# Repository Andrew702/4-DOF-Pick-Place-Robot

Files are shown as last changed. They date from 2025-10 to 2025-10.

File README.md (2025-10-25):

# 📦 4-DOF Pick & Place robotic arm

_A 4DOF scara robot with a gripping head for picking and placing products in an assembly line_

---

## 🧠 Overview

- This is my project fot the robotics, automatic control, and MCT system design courses, it uses simple manufactured parts and cheap components.
- A study for actuator sizes is done as the model is exported to matlab.
- We use ROS for manipulating the Arm efficiently.

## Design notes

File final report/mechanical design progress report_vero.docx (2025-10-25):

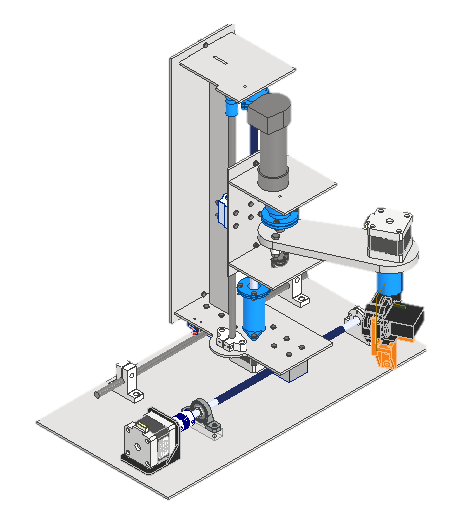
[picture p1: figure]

Mechatronics System Design

Name | ID
Andrew Hany Sobhy | 1900440
Abanoub Masrour Mehawed | 1901055
Veronia Ibrahim Mikhael | 1900463
John Sameh Sobhi | 1900907
Caren Mahrous Zakhary | 1901503
Zyad Wahied Kamel | 1700575

mechanical design report

submitted to:

Eng. Hossam Elkeshky

Eng. Mohab Ahmed

Eng. Zeyad Hazem

# Introduction

# 1. Robots in industrial field

An industrial robot is an autonomous system of sensors, controllers, and actuators on an articulated frame that executes specific functions and operations in a manufacturing or processing line. They operate continuously through repetitive movement cycles as instructed by a set of commands called a program. These machines minimize or eliminate the human factor to gain various advantages in processing speed, capacity, and quality.

# 1. What is a VDI model

Figure 1 VDI model

# VDI Model

# 1. System Requirements

1. The robot weight is less than 7.5 kg

2. size must not exceed 0.04 cubic meter

3. graphical user interface: user friendly

# 2. System design

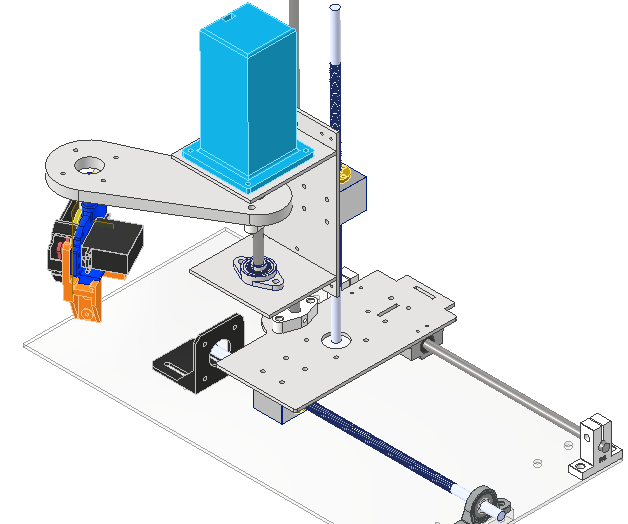
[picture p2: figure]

For the system some decisions were taken according to the system requirements as

1. The 4 degrees of freedom will be divided into 2 prismatic joints (motion in x-axis , motion in z-axis) and 2 revolute joints (rotation about z-axis, rotation about end effector z-axis )
2. Application for robot is pick and place.
3. Number of motors → 5
1. Dc motor with encoder for the revolute joint
2. 3 stepper motors
3. Servo motor for the end effector
4. A microcontroller is needed to control the motor and its motion. (Arduino)
5. A PCB must be implemented to insure firm wiring.
6. ROS will be used as a communication protocol between microcontrollers and other electronic devices.

# 2. Domain specific design

## 1. Mechanical design

### 1. Joint #1 (Prismatic):

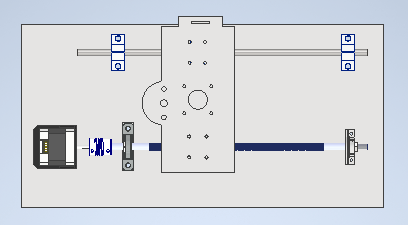
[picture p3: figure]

- Design:

Figure 2 joint 1 isometric view

Figure 3 joint 1 plan view.

- Operation and support:

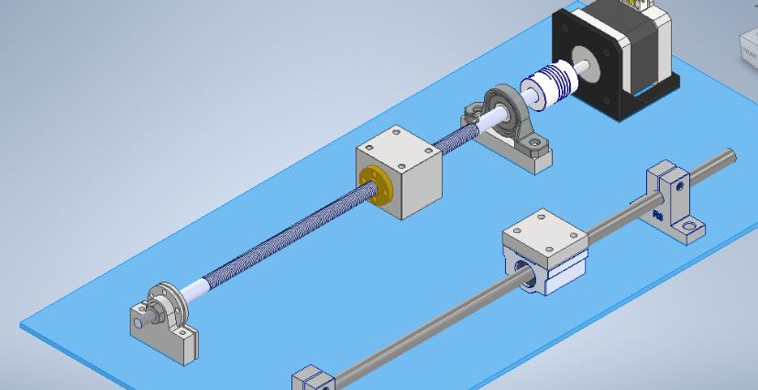
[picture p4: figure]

- Motion is Governed by a nema 17 motor coupled to a lead screw and guide nut to transform rotational motion into translational motion to carry the base in the Y Axis direction.

Figure 4 joint 1 motion

- Bearings used : 3 ( 2 ball bearing , 1 linear bearing)
- Lead Screw and motor shaft are supported by 2 Plummer blocks at each end of the lead screw and the base is moved along a supporting rod attached jointed by a linear bearing.

Figure 5 joint 1 motor support floating bearing

- Motor support:
  1. floating bearing:
- motion is transmitted to the lead screw using coupling between motor shaft and lead screw.
- Plummer block is used as the floating bearing.
  2. Fixed bearing:

Deep grove ball bearing fixed from 4 points ( shoulder

in lead screw, 2 shoulder in bearing cover, Nut)

Figure 6 joint 1 motor support fixed bearing

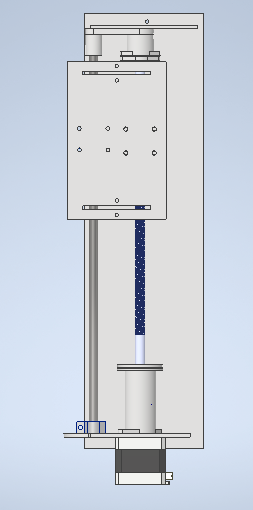
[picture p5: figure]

### 2. Joint #2 (Prismatic):

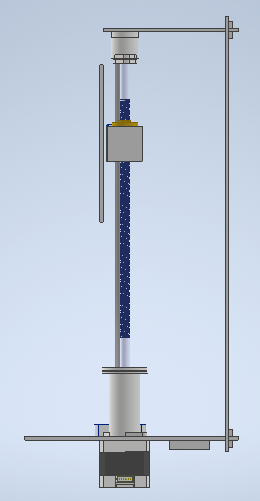
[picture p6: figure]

- Design:

Figure 7 joint 2 front view

Figure 8 joint 2 side view

Figure 9 joint 2 isometric view

- Operation and support

Motion is Governed by a nema 17 motor coupled to a lead screw and guide nut to transform rotational motion into translational motion to carry the Revolute joint in the Z Axis direction .

Revolute joint is attached to the cart by guide nut housing and Linear bearing block Via bolts and nuts , The cart is also supported on a linear rod.

- Motor support
- Fixed

Deep Groove ball bearing Fixed on 4 points by ( Snap Ring , Housing shoulder, Power screw shoulder ,Cover)

Figure 10 joint 2 motor support fixed bearing

- Floating

Deep Groove ball bearing Fixed on 2 points by (Housing Shoulder, Cover)

Figure 11 joint 2 motor support floating bearing

### 3. Joint #3 (Revolute):

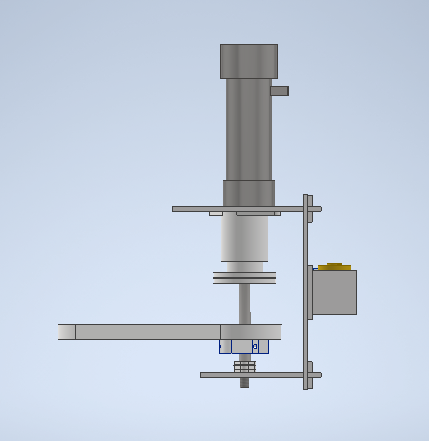
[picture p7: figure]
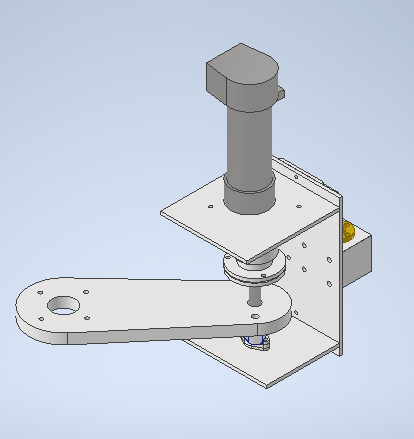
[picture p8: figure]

- Design:

Figure 12 joint 3 isometric view

Figure 13 joint 3 side view

- Operation and support:

Motion is Governed by a DC motor coupled to a rod and the rotation of rod is transferred to the joint by a pin connection to rotate around Z axis.

- Motor Support:
- Fixed

Deep Groove ball bearing Inside a flanged cover Fixed on 4 points by ( Nut, Housing shoulder, Power screw shoulder, Cover)

Figure 14 joint 3 motor support fixed bearing

- Floating

Figure 15 motor support floating bearing

Deep Groove ball bearing Fixed on 2 points by (Housing Shoulder, Cover)

### 4. Joint #4 (Revolute & End Effector):

- Design:

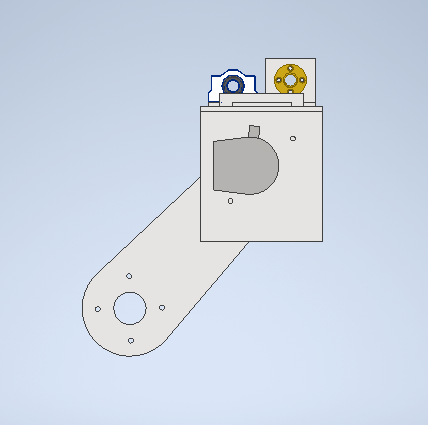
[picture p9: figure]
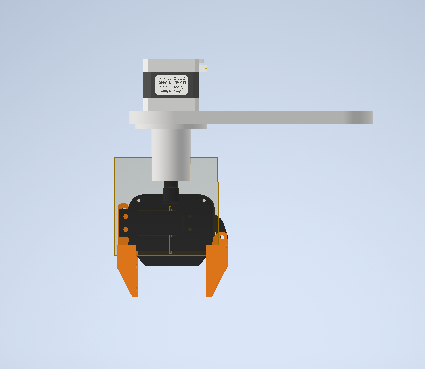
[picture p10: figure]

Figure 16 joint 4 side view

Figure 17 joint 4 plan view

- Operation and support:

Motion is Governed by a Nema 17 motor coupled to End Effector shaft to allow the end effector to rotate around Z axis .

End Effector has a servo motor attached to it to control the gripping action.

- Motor support:

Figure 18 joint 4 motor support bearing

Thrust ball bearing Inside a cover fixed on 2 points by (Coupler, Housing shoulder)

### 5. Bill of material:

component | qty | cost | store | specifications
lead screw | 2 | 60 | lancer | 30cm , 8mm
nut block | 2 | 70 | lancer | 8mm
lead screw nut | 2 | 30 | lancer | 2starts, 8mm
shaft | 3 | 40 | uge_helo. | 8mm * 333 length
linear bearing block | 2 | 50 | lancer | 8mm
vertical shaft support | 2 | 60 | | 8mm , 3d printing
horizontal shaft support | 2 | 60 | | 8mm , 3d printing
plumer block horizontal | 1 | 0 | | 6mm , 3d printing
plumer block horizontal | 1 | 40 | lancer | 8mm
plumer block vertical | 1 | 0 | | 6mm , 3d printing
Linear gripper | 1 | 0 | | End Effector 3d printing
nema 17 holder | 1 | 40
coupler 5*8 | 1 | 45 | lancer
coupler 6.35*10 | 1 | 70 | future | 10 OOS , 8 Available
nema 17 | 1 | 60 | lancer | used, 2 left
dc motor | 1 | 0 | john
Servo motor | 1 | 0 | caren
Nema 17 cable with Dupont | 1 | 20 | lancer
A4988 Driver | 1 | 50 | lancer | 2left
ball bearing (8*16) | 2 | 20 | twfi2ia | width 4
ball bearing (6*13) | 1 | 20 | twfi2ia | width 3.5
ball bearing (6*19) | 1 | 20 | twfi2ia | width 6
thrust bearing (10*24) | 1 | 20 | twfi2ia | width 9
snap ring | 1 | 0 | | shaft 6
bolts M4*1.6 | 8 | 1 | lancer
nema 17 screw set | 10 | 1 | lancer
bolts M3*1 | 8 | 1 | lancer
M6 nuts | 2 | 0

## 2. Actuator Sizing

### 1. Motor 1

Figure 19: motor 1 in matlab view

Type: Stepper motor (so we don’t need feedback or encoder to achieve accurate positioning with high torque)

Inertia: J_(horizontal cart) +J_(leadscrew asm) +J_(rotor) =9.8×10^(-6) kg.m^2

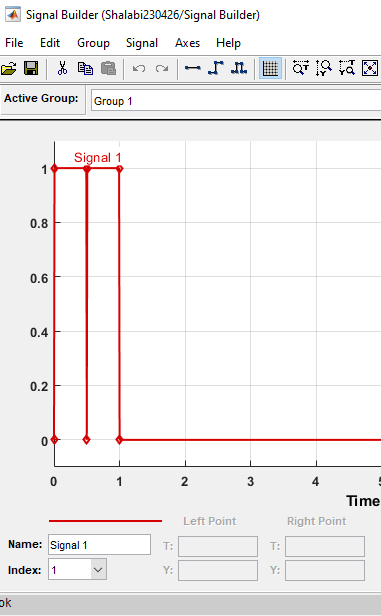
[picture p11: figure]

Motion Profile:

Figure 20: Velocity Profile for motor 1

- max velocity = 300 rpm = 31.41 rad/s
- signal is in the form of trapezoidal pulses with acceleration time = 0.0077 seconds.

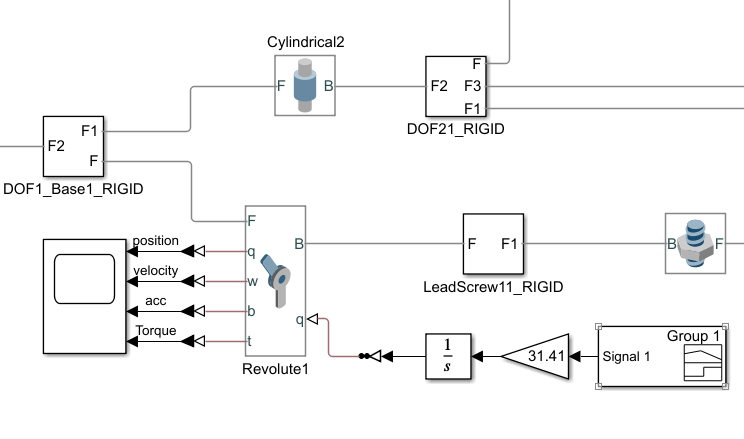
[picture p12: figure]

Figure 21: Connection configuration for motor 1

Figure 22: Torque Profile for motor 1

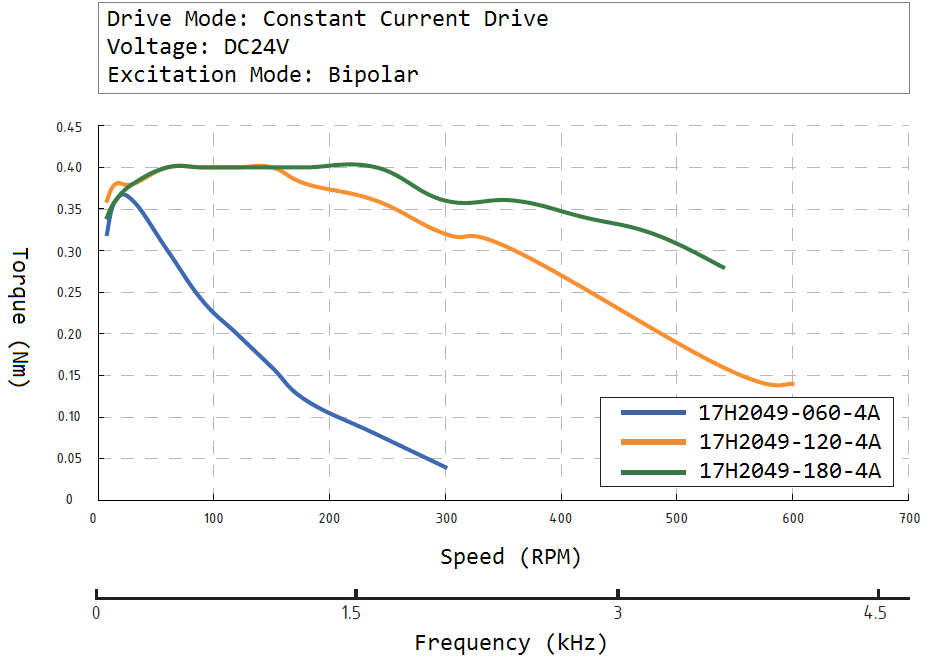
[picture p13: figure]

Torque: As we can see from the graph above the peak torque is at 0.04 N.m, one stepper motor that’s suitable for this torque at 300 rpm is the NEMA-17H2049-060-4A, which will provide a maximum speed of 300 rpm this gives us an acceleration time of 0.0077 seconds as mentioned above and the velocity profile matches exactly, except for the number of steps (pulses) given to the motor each second (2 steps are only demonstrated).

Figure 23: NEMA-17 Torque Speed characteristics

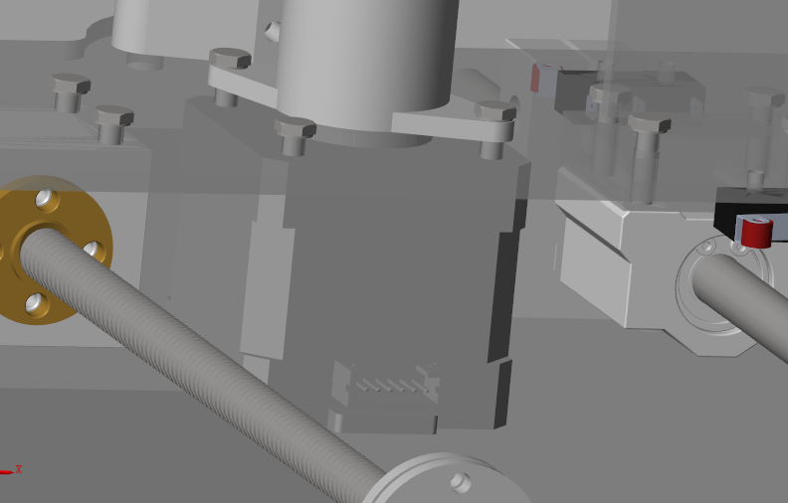
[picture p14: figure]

### 6. Motor 2

Figure 24: motor 2 in matlab view

Figure 25: motor 2 another view

Type: Stepper motor (so we don’t need feedback or encoder to achieve accurate positioning with high torque)

Inertia: J_(vertical cart) +J_(leadscrew asm) +J_(rotor) =9.72×10^(-6) kg.m^2

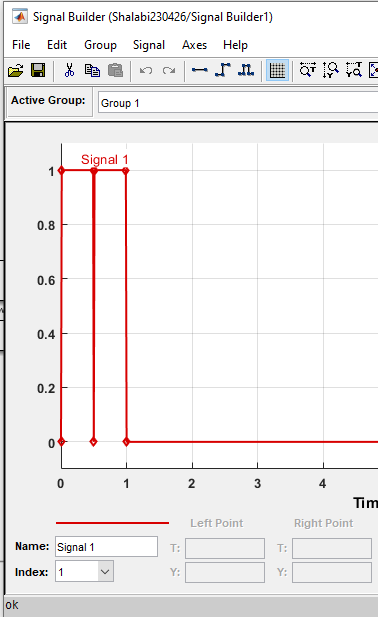
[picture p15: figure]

Motion Profile:

- max velocity = 300 rpm = 31.41 rad/s

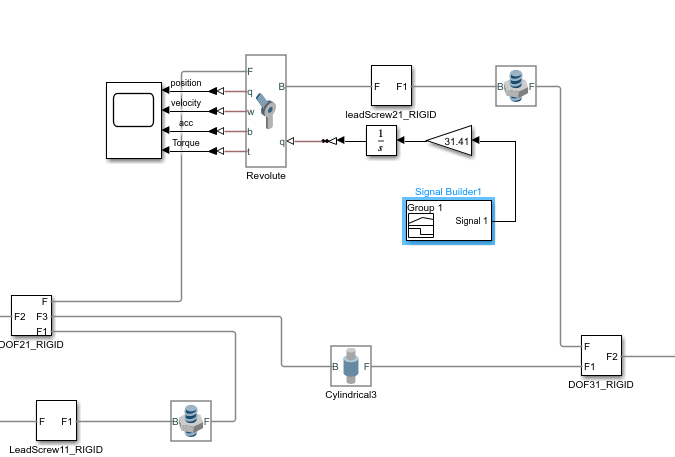
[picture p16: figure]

- signal is in the form of trapezoidal pulses with acceleration time = 0.01137 seconds.

Figure 26: Figure 27: Connection configuration for motor 2

Figure 28: Velocity Profile for motor 2

Figure 29: Torque Profile for motor 2

Torque: As we can see from the graph above the peak torque is at 0.04 N.m, at also 300 rpm this allows us to also use the NEMA-17 stepper motor as motor 1 (2 steps are only demonstrated in the above graph).

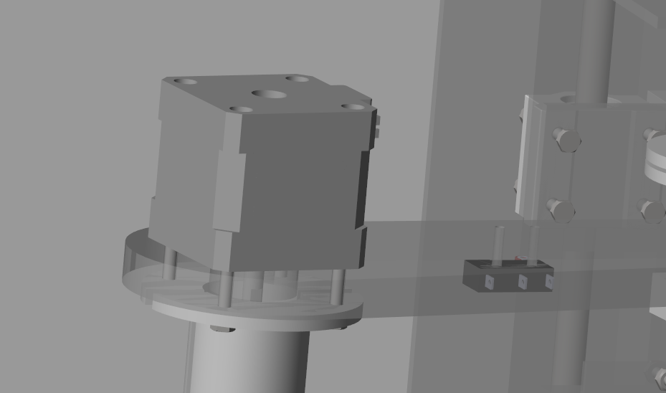
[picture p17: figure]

### 7. Motor 3

Figure 30: motor 3 in matlab view

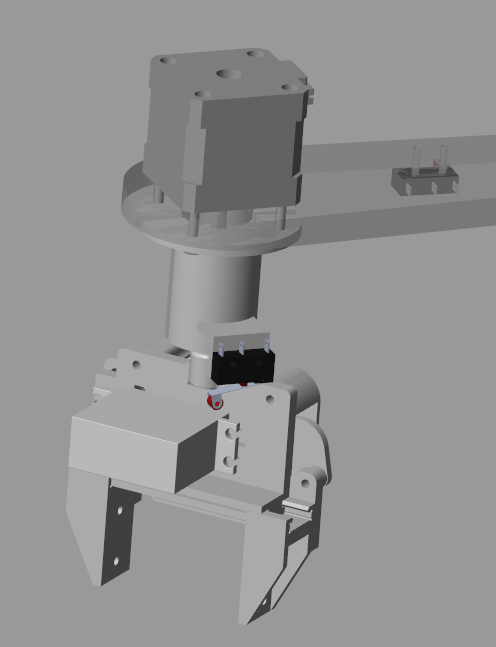
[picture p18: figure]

Figure 31: motor 3 another view

Type: Stepper motor (so we don’t need feedback or encoder to achieve accurate positioning with high torque)

Inertia: J_(Coupler+gripper) +J_(rotor) =9.88×10^(-5) kg.m^2

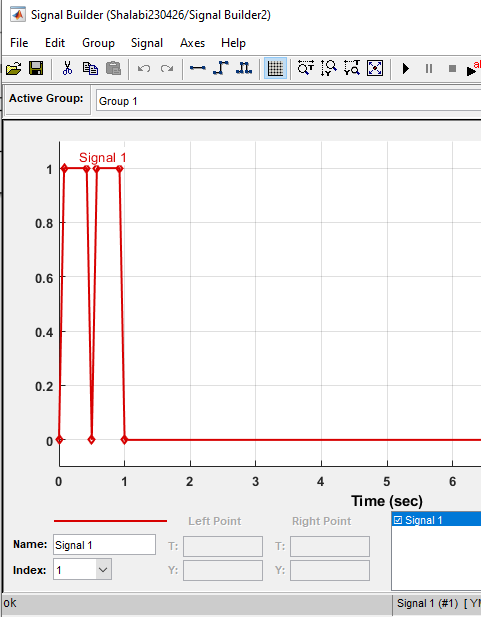
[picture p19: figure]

Motion Profile:

Figure 32: Figure 33: Figure 34: Connection configuration for motor 2

- max velocity = 300 rpm = 31.41 rad/s
- signal is in the form of trapezoidal pulses with acceleration time = 0.07758 seconds.

Figure 35: Figure 36: Velocity Profile for motor 3

Torque: As we can see from the graph above the peak torque is at 0.04 N.m, at also 300 rpm this allows us to also use the NEMA-17 stepper motor as motors 1 and 2 (2 steps are only demonstrated in the above graph).

## 3. Electrical design

### 1. PCB design

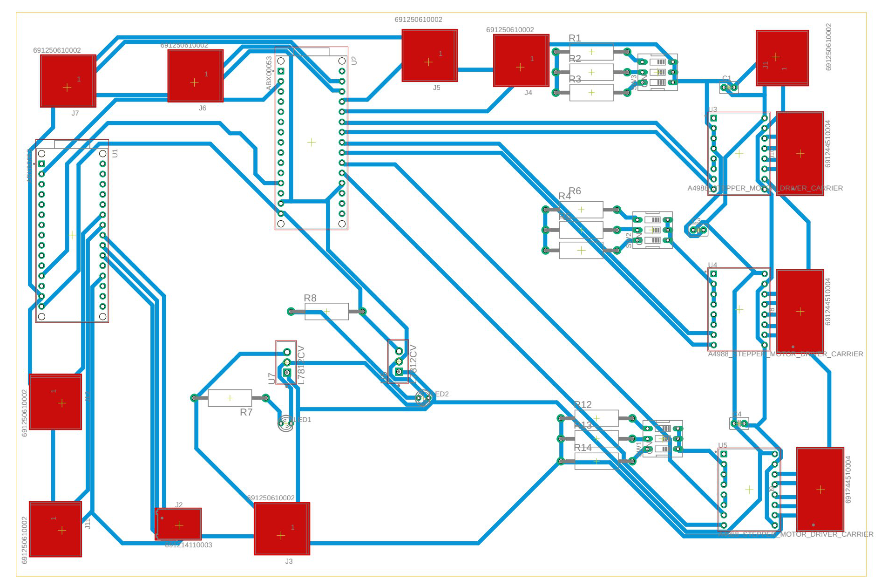
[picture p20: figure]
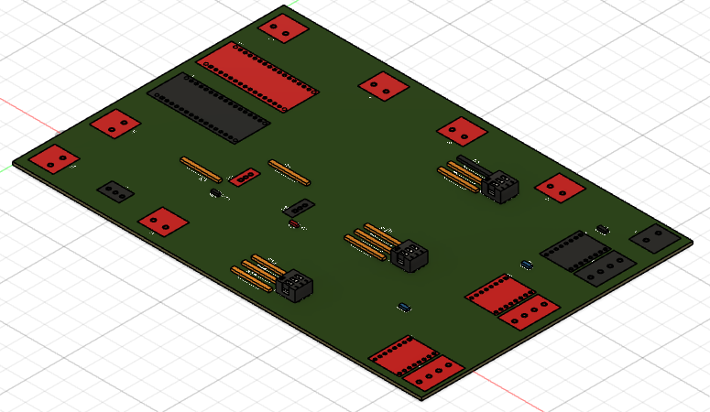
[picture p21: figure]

Figure 37 PCB layout

Figure 38 PCB 3d model

Figure 39 PCB schematic

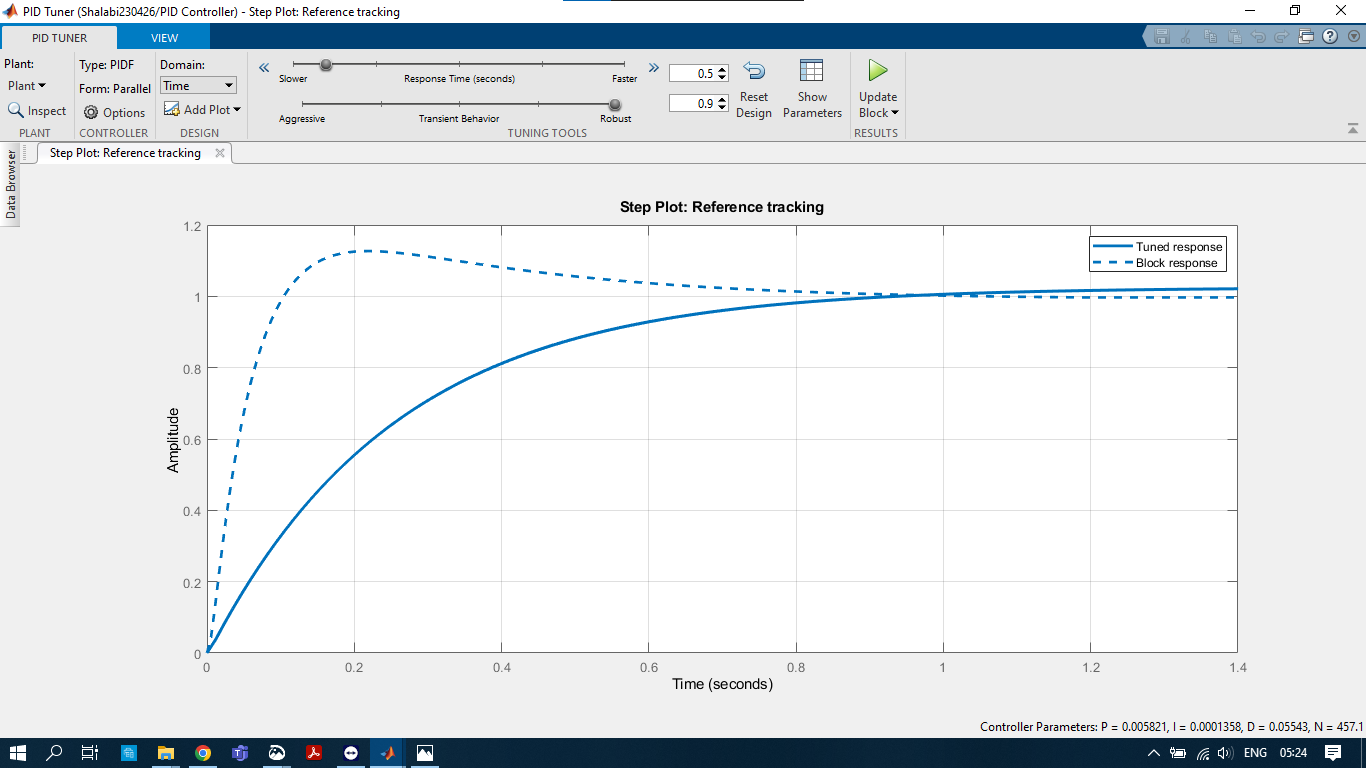
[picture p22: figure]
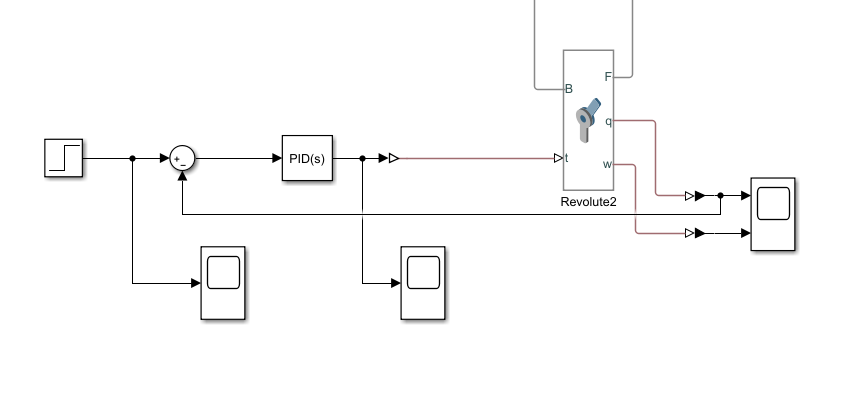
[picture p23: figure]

### 8. PID:

Figure 40 PID using Simulink

Figure 41 Tuning PID

Figure 42 PID Block parameter

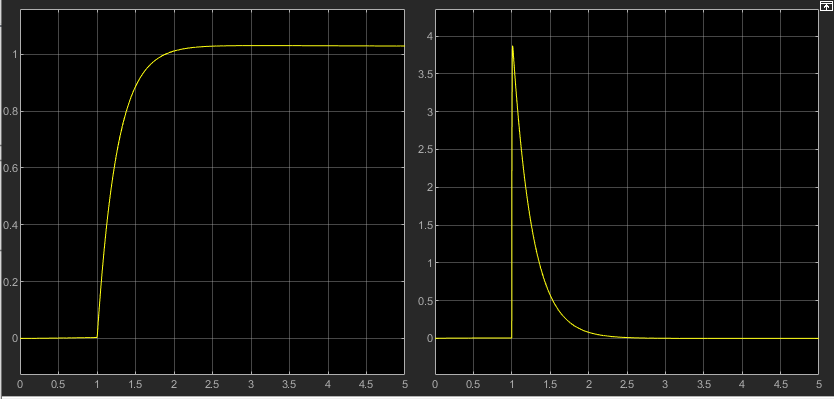
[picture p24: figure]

Figure 43 PID output curves ( position , speed)

Course code: MCT333s 2 Course name: Mechatronics system design project Robotic arm 4DOF

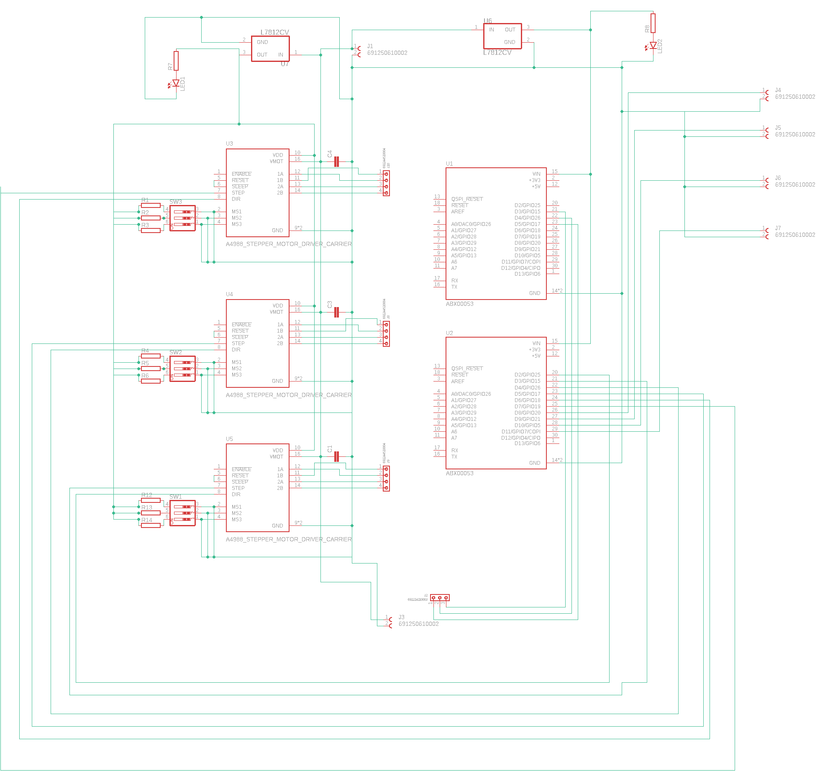
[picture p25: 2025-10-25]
PCB/Schematic.png

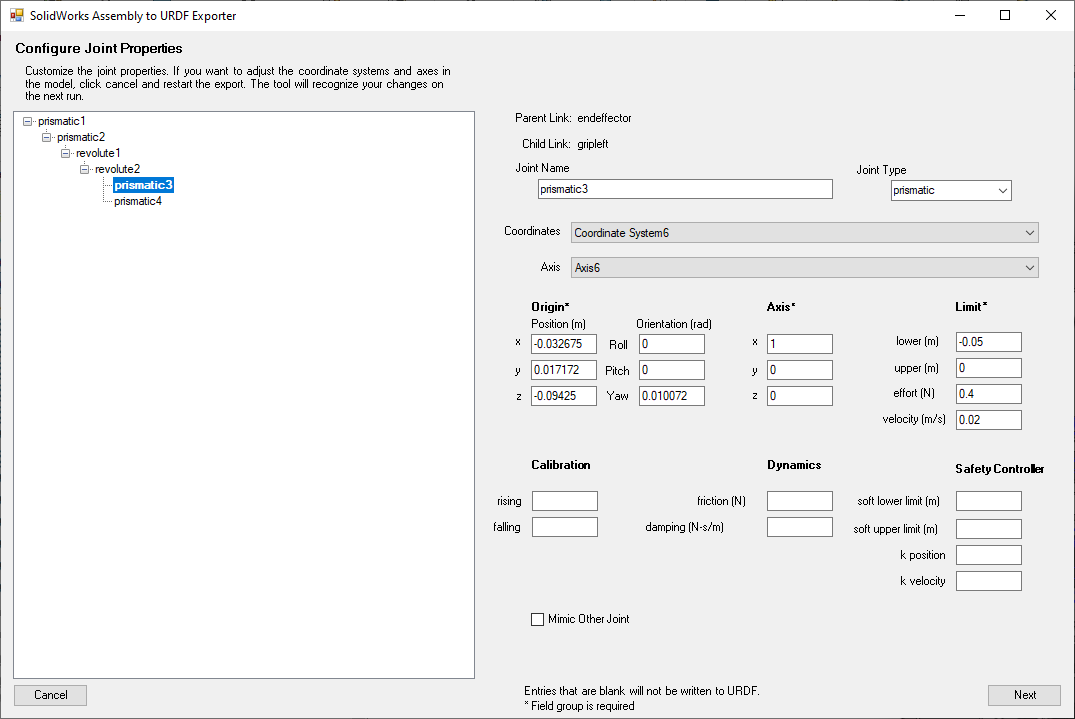
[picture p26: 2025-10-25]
URDF_Config/Capture5.PNG

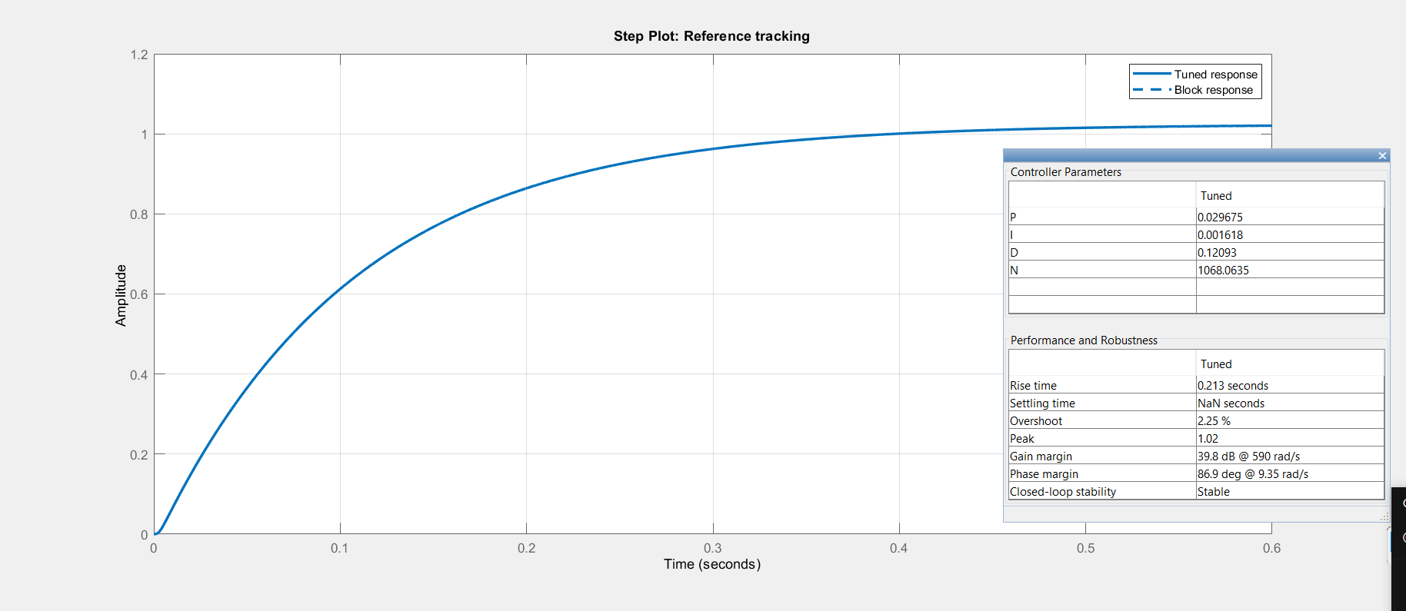
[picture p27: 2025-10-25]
screen shots/pid1.PNG

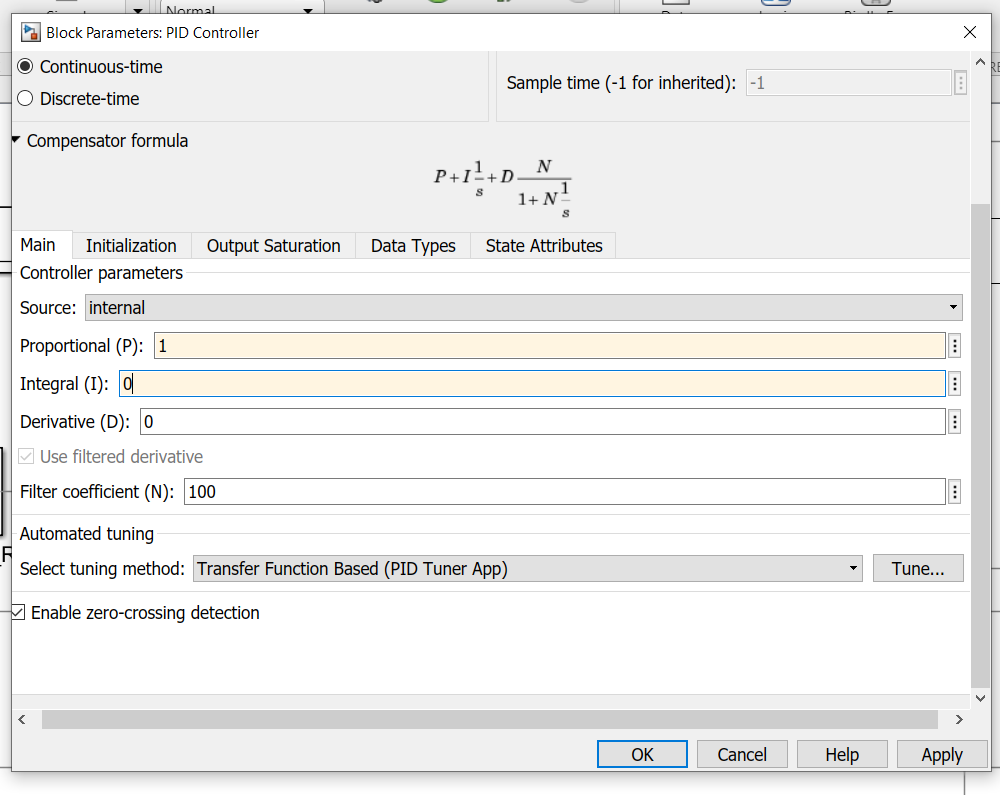
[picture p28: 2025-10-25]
screen shots/pid0.PNG

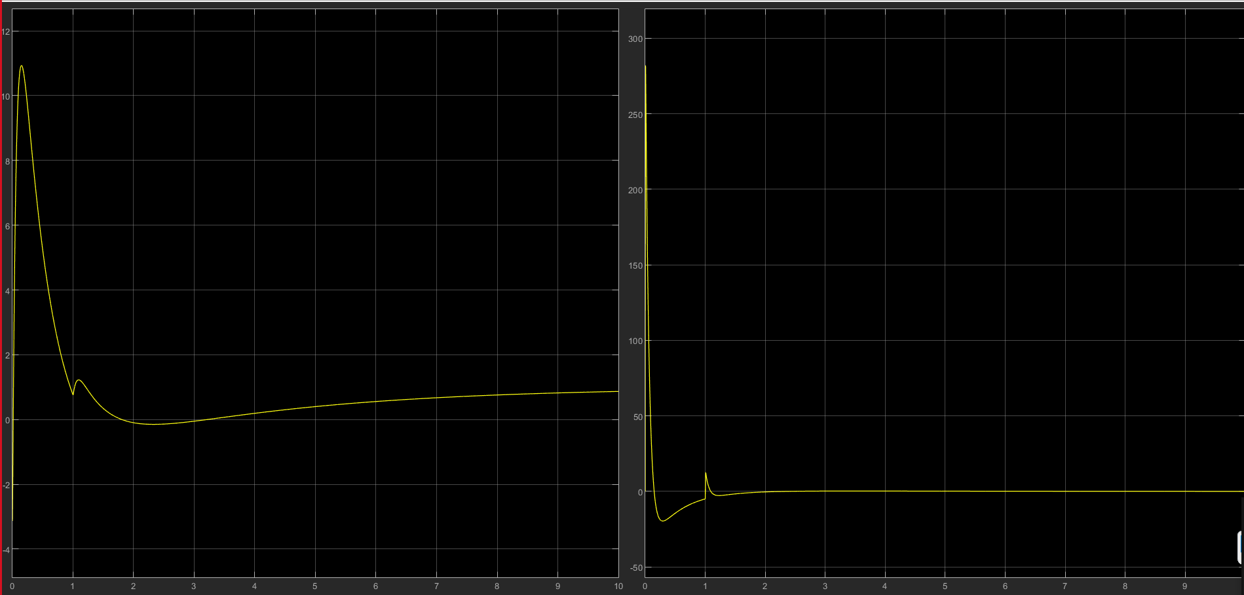
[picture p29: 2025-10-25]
screen shots/pid scope final.PNG

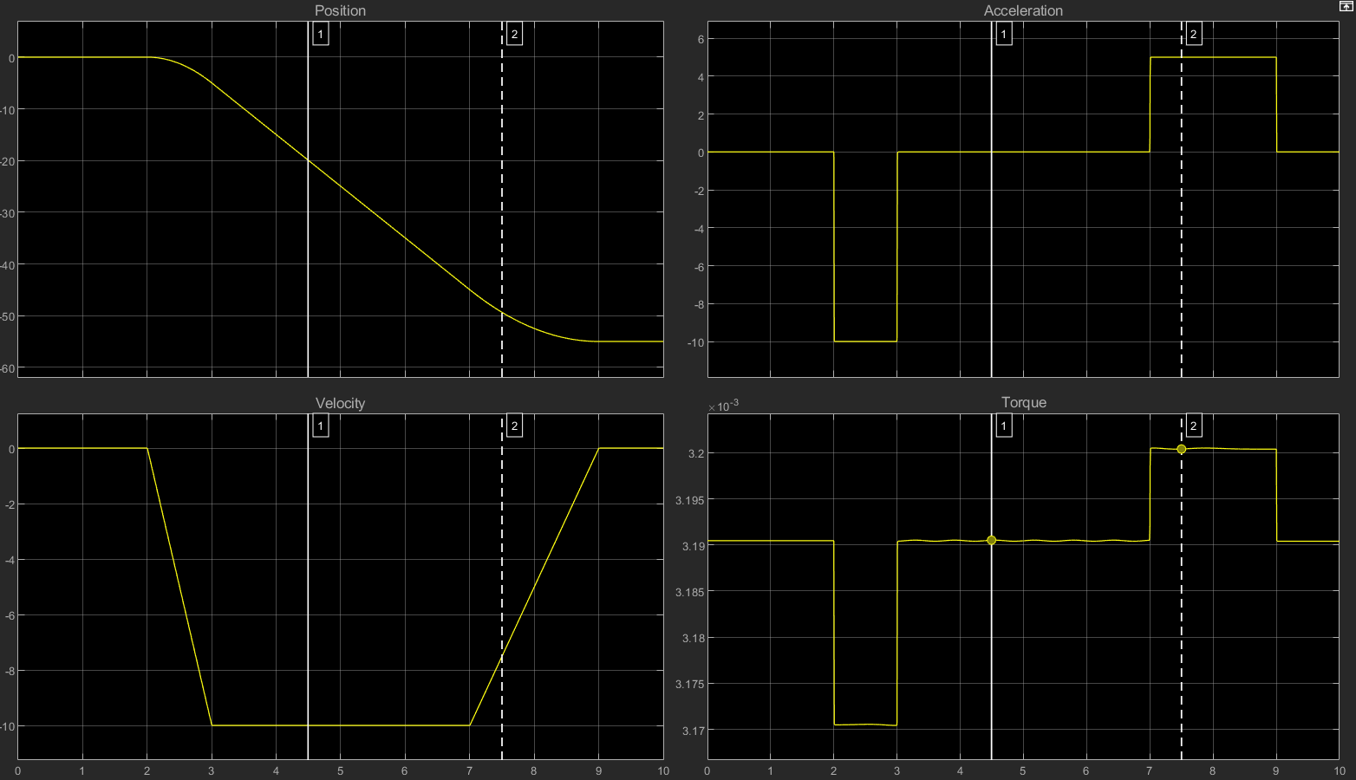
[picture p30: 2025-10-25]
screen shots/hm_scopeout.PNG

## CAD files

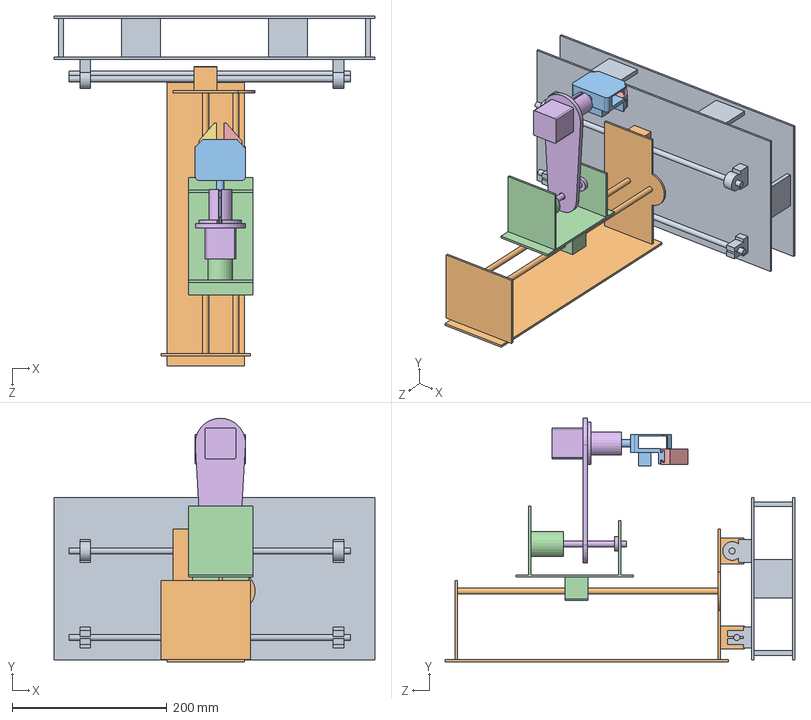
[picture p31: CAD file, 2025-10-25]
ROS/Shalabi1.SLDASM
415.0 x 314.9 x 452.0 mm
base_link
horizontalcart
endeffector
verticalcart
gripleft
RevoluteArm
gripright

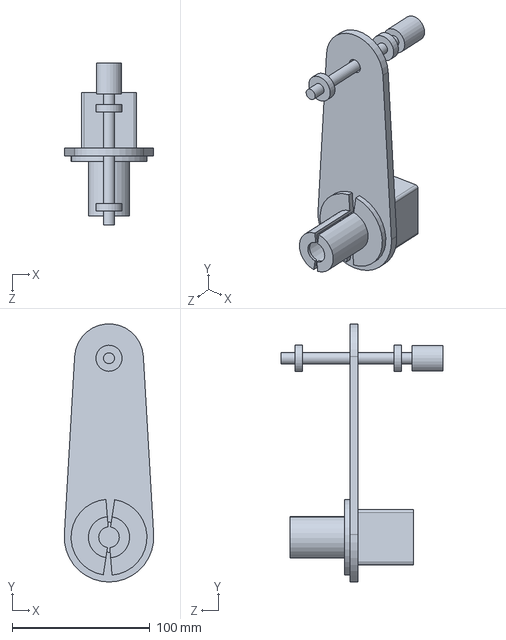
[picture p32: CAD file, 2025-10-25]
ROS/RevoluteArm.SLDPRT
64.9 x 187.4 x 117.3 mm

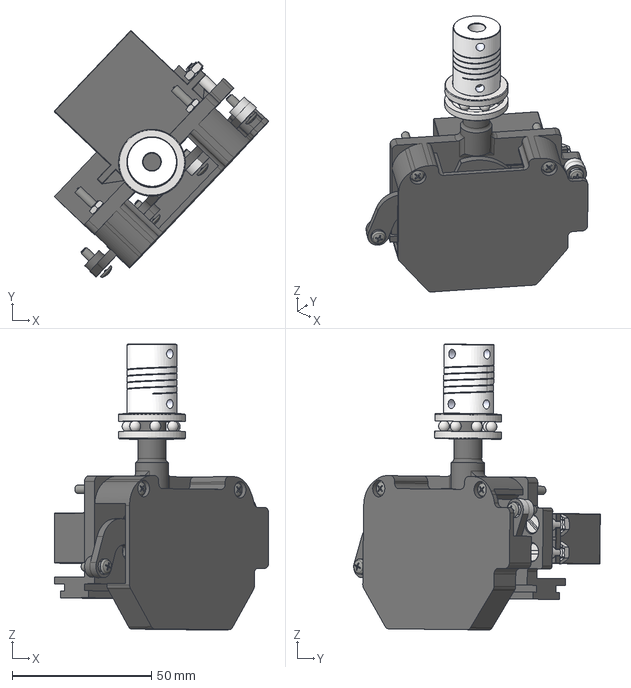
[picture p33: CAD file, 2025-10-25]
SLExport/EndEffector base part.stp
77.0 x 88.6 x 102.7 mm

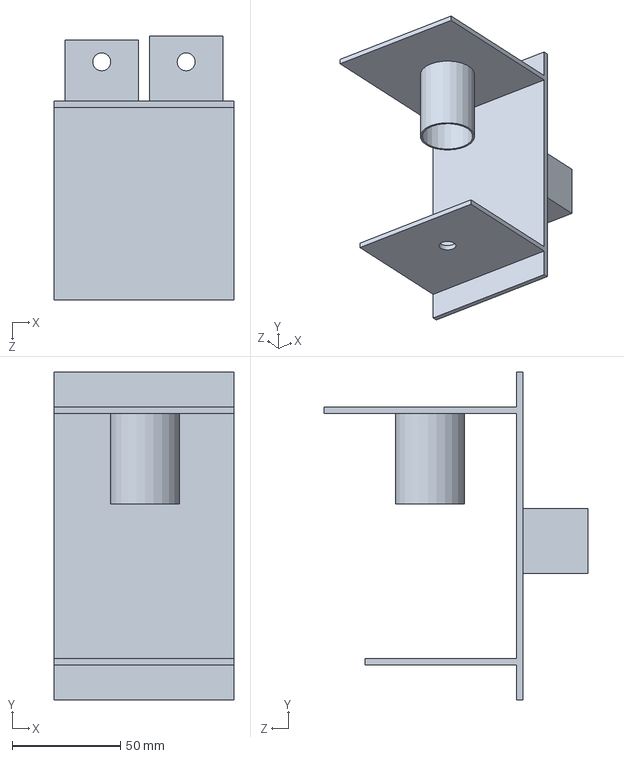
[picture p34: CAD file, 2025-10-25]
ROS/verticalcart.SLDPRT
83.0 x 151.4 x 122.0 mm

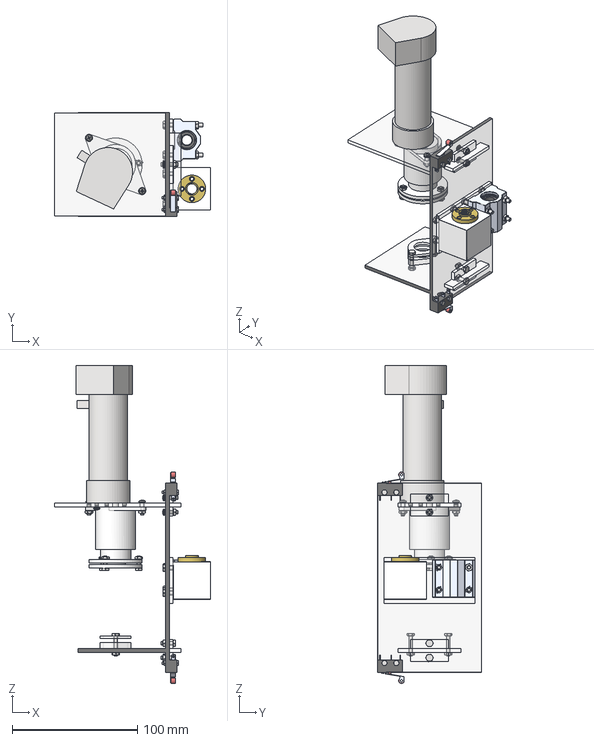
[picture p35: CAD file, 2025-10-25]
SLExport/Prismatic_2.stp
125.0 x 83.0 x 254.2 mm

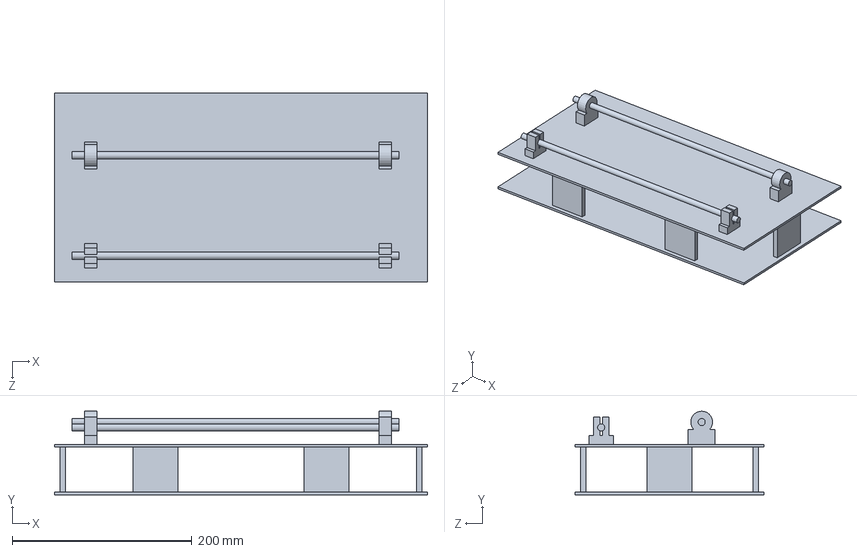
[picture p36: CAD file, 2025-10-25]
ROS/base_link.SLDPRT
415.0 x 93.2 x 210.0 mm

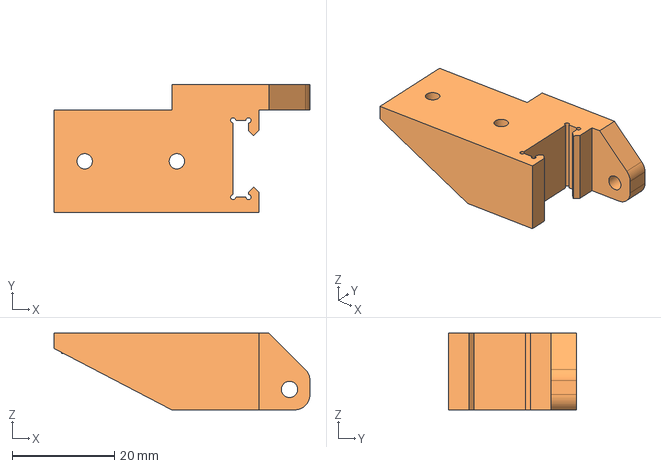
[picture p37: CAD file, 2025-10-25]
SLExport/grip arm.stp
50.0 x 25.0 x 15.0 mm

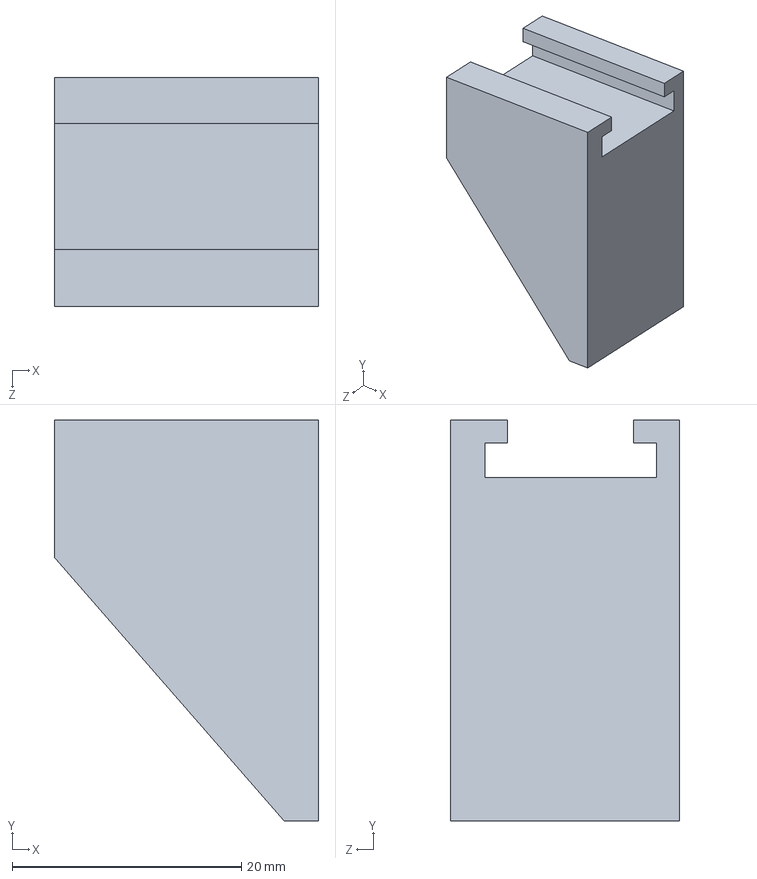
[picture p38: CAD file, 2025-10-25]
ROS/gripright.SLDPRT
23.1 x 35.0 x 20.0 mm

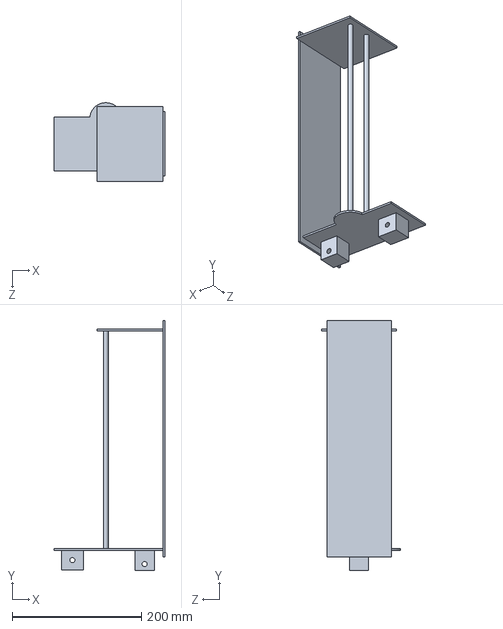
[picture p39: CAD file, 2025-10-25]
ROS/horizontalcart.SLDPRT
171.5 x 387.0 x 122.0 mm

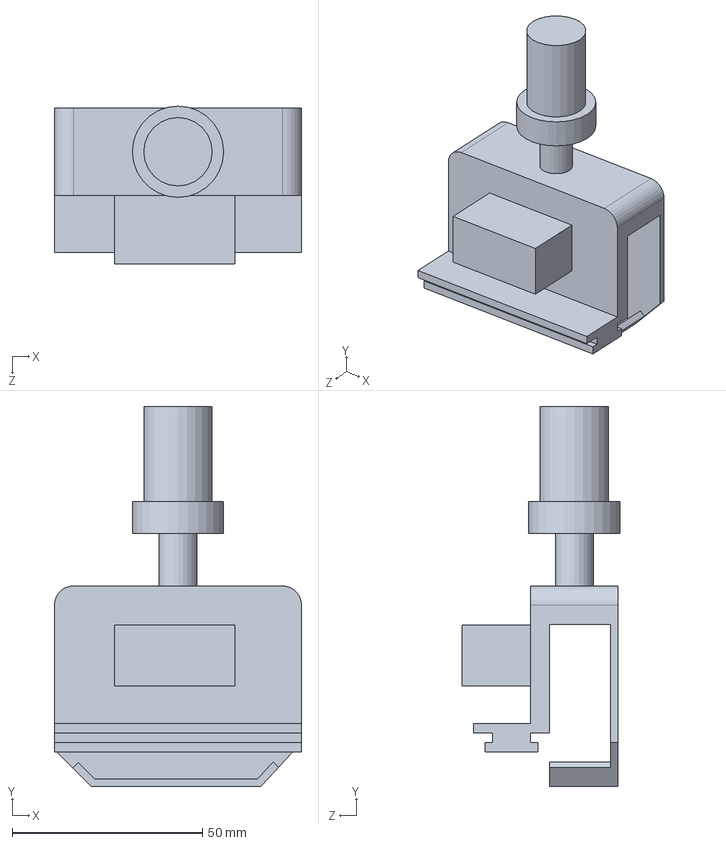
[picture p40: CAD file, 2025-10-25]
ROS/endeffector.SLDPRT
65.0 x 100.0 x 41.5 mm

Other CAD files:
SLExport/Mirrorgrip arm.SLDPRT
ROS/gripleft.SLDPRT
ROS/Mirrorgripleft.SLDPRT
SLExport/EndEffector base part.SLDPRT
SLExport/Prismatic_2.SLDPRT
SLExport/grip arm.SLDPRT

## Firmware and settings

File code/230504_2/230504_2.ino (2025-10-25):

#define Angle 0
#define Distance 1
#define CW 1
#define CCW 0

// PINS DEFINITIONS
const int enPin=8;
const int step1Pin = 2; //X.STEP
const int dir1Pin = 5; // X.DIR
const int step2Pin = 3; //Y.STEP
const int dir2Pin = 6; // Y.DIR
const int step3Pin = 4; //Z.STEP
const int dir3Pin = 7; // Z.DIR

int dirPin, stepPin;
unsigned int steps;


int pulseWidthMicros = 100; 
int microsBtwnSteps = 1000;


//Flags
bool stepperenabled = 0;

unsigned long previousTime[2] = {0}; // variable to store the previous time for each delay
unsigned long delayTime[2] = {100, 1000}; // delay times in microseconds
unsigned long currentTime;

bool checkMicroDelay(int index) {
  currentTime = micros(); // get the current time in microseconds
  if (currentTime - previousTime[index] >= delayTime[index]) { // check if the desired delay has elapsed
    previousTime[index] = currentTime; // update the previous time
    return true; // return true if the delay has elapsed
    }
  return false; // return false otherwise
}

void setup() {
  // put your setup code here, to run once:
  SteppersInitialize(); //function to initialize steppers as output pins
  SetStepperMove(1,Distance,100,CW);
}

void loop() {
  // put your main code here, to run repeatedly:
  StepperMove();
}


void SteppersInitialize(void) //function to initialize steppers as output pins
{
  pinMode(enPin, OUTPUT);
  digitalWrite(enPin, LOW);

  pinMode(step1Pin, OUTPUT);
  pinMode(dir1Pin, OUTPUT);
  pinMode(step2Pin, OUTPUT);
  pinMode(dir2Pin, OUTPUT);
  pinMode(step3Pin, OUTPUT);
  pinMode(dir3Pin, OUTPUT);
}

void SetStepperMove(int StepperNo, bool operating_option, float position, bool direction)
{
  // position is specified in mm, angle is in degrees
  //if operating operation = 0 ---> angle
  //if operating operation = 1 ---> distance
  //if direction = 1 ---> clockwise/up/forward
  //if direction = 0 ---> anticlockwise/down/backward
  //---------------------------------------------------------------------------------------

  float angle;

  if(operating_option) // in mm
  {
    angle = (360*position)/4; // lead is 4mm
    steps = angle/1.8;
  }
  else
  {
    steps = position/1.8;
  }

  if(StepperNo == 1)
  {
    stepPin = step1Pin;
    dirPin = dir1Pin;
  }
  else if(StepperNo == 2)
  {
    stepPin = step2Pin;
    dirPin = dir2Pin;
  }
  else if(StepperNo == 3)
  {
    stepPin = step3Pin;
    dirPin = dir3Pin;
  }

  if(direction)
     digitalWrite(dirPin, HIGH);
  else
    digitalWrite(dirPin, LOW);

  stepperenabled = 1;
  
}

void StepperMove()
{ 
  {
    //start motion
    static int i  = 0;
    static bool flag = 0;

    if(i<steps)
    {
      if(!flag)
      {
        if(stepperenabled)
         {digitalWrite(stepPin, HIGH);}
        if(checkMicroDelay(1))
        {
            digitalWrite(stepPin, LOW);
          flag = 1;
          previousTime[2] = currentTime;
        }
      }
      else if(flag)
      {
        if(checkMicroDelay(2))
        {
          flag = 0;
          previousTime[1] = currentTime;
          i++;
        }
      }
    }
    else
    {
      i = 0;
      stepperenabled = 0;
    }
  }
}

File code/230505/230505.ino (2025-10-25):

#include <AccelStepper.h>
#include <MultiStepper.h>


const int enPin=8;
const int step1Pin = 2; 
const int dir1Pin = 5; 
const int step2Pin = 3;
const int dir2Pin = 6; 
const int step3Pin = 4;
const int dir3Pin = 7;

const int steps_per_revolution = 200;

AccelStepper Stepper1(AccelStepper::DRIVER, step1Pin , dir1Pin);
AccelStepper Stepper2(AccelStepper::DRIVER, step2Pin , dir2Pin);
AccelStepper Stepper3(AccelStepper::DRIVER, step3Pin , dir3Pin);

volatile int step_count = 0;


int command = 0;

void Stepper1Move(int position);


void setup() {

  pinMode(enPin, OUTPUT);
  digitalWrite(enPin, LOW);

  Stepper1.setMaxSpeed(500);
  Stepper1.setAcceleration(250);
  Stepper2.setMaxSpeed(500);
  Stepper2.setAcceleration(250);

  // set the initial position of the stepper motor
  Stepper1.setCurrentPosition(0);
  Stepper2.setCurrentPosition(0);

  Serial.begin(9600);

}

void loop()
{

  if(Serial.available())
  {
    command = Serial.parseInt();
  }

 /* if(command == '1')
    {
    Stepper1Move(1000);
    Stepper2Move(600);
    }
  else if(command == '2')
    {
      Stepper1Move(0);
      Stepper2Move(0);
    }
*/
  if(command)
  Stepper1Move(command); 

  if(!Stepper1.run())
  {
    digitalWrite(enPin, HIGH);
  }

}

void Stepper1Move(int position)
{
  digitalWrite(enPin, LOW);
  Stepper1.moveTo(position);
}
/*void Stepper2Move(int position)
{
  digitalWrite(enPin, LOW);
  Stepper2.moveTo(position);
}
*/
